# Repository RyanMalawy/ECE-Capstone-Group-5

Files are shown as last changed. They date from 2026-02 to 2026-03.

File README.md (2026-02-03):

# Shoe Insole Pressure Sensor PCB
Schematic and Board Layout for Mizzou ECE Capstone Project

ESP 32 Code

## Repository Rules
When pushing KiCad files, do not push .lck files

## Toolchain
KiCad Version: 9.0

Arduino IDE

## Repository Structure
| Path | Description |
|---|---|
| /Capstone-backups | .zip backups |
| /Hierarchical Sheets | .kicad_sch files |
| /Spice | .kicad_sch files with Spice |
| /Libs | Any imported IC models |
| Capstone.kicad_sch | Root schematic file |
| Capstone.kicad_pro | Project file |
| Capstone.kicad_pcb | PCB file |

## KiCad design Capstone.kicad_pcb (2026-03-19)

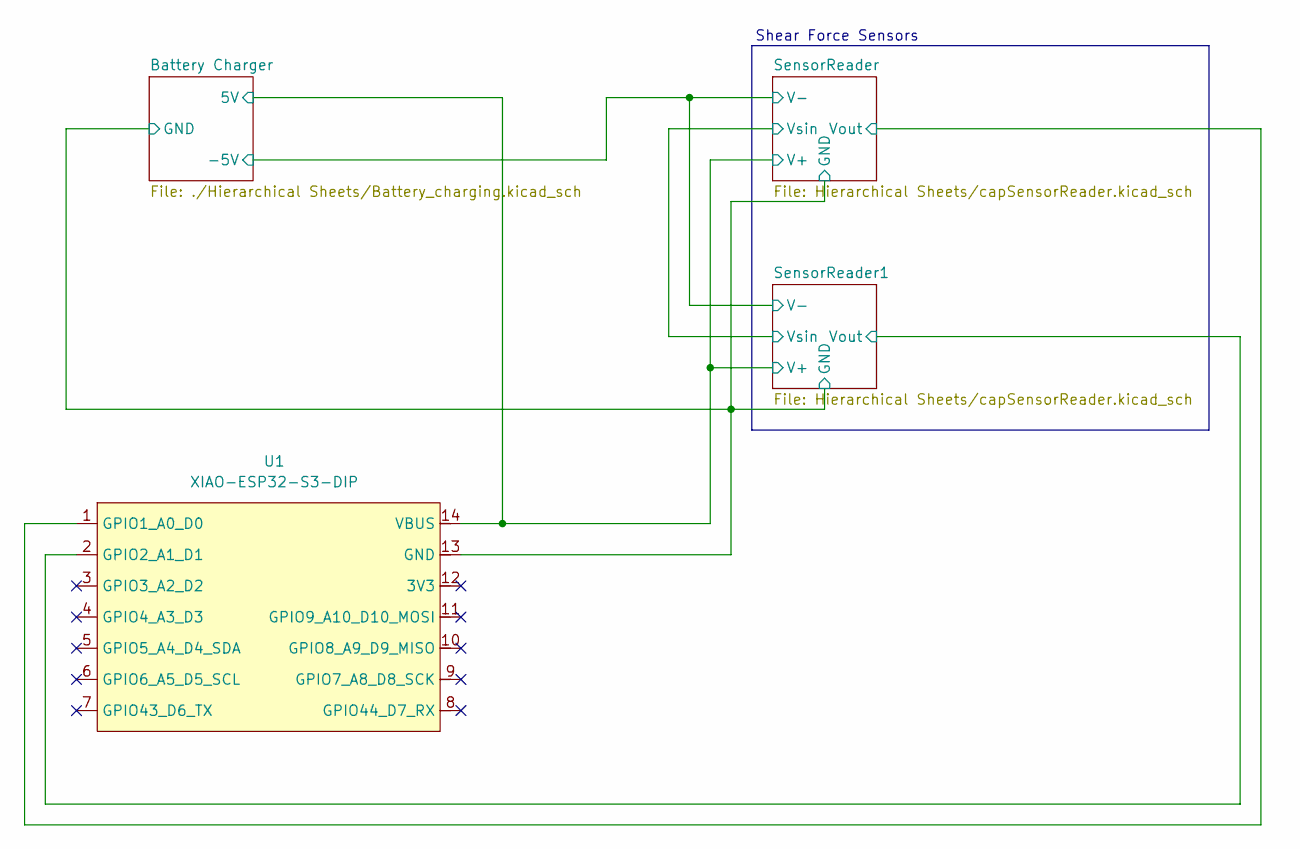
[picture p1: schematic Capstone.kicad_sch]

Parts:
U1: XIAO-ESP32-S3-DIP

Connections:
5V OUT: U1.14 (VBUS); also elsewhere on the board
/SensorReader1/Vout: U1.2 (GPIO2_A1_D1); also elsewhere on the board
/SensorReader/Vout: U1.1 (GPIO1_A0_D0); also elsewhere on the board
GND: U1.13 (GND); also elsewhere on the board

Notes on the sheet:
Shear Force Sensors

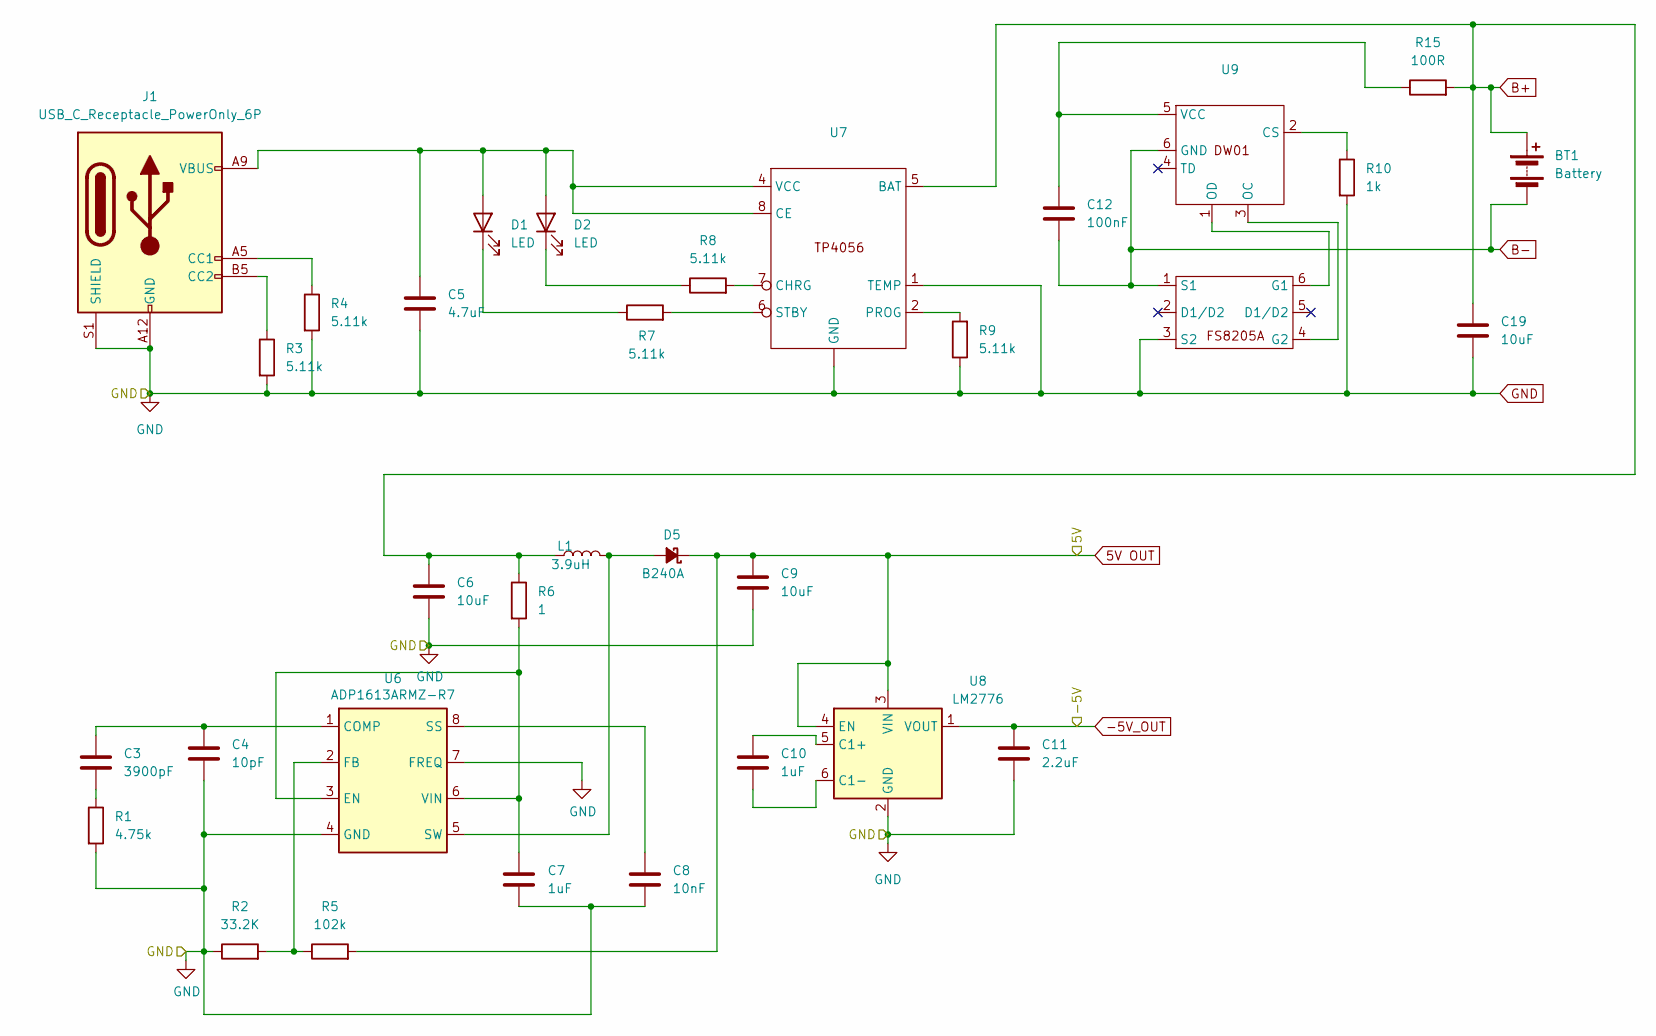
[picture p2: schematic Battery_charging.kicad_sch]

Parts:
BT1: Battery; JST_SUR_BM02B-SURS-TF_1x02-1MP_P0.80mm_Vertical
C3: 3900pF; C_Disc_D3.8mm_W2.6mm_P2.50mm
C4: 10pF; C_Disc_D3.8mm_W2.6mm_P2.50mm
C5: 4.7uF; C_Disc_D3.8mm_W2.6mm_P2.50mm
C6, C9, C19: 10uF; C_Disc_D3.8mm_W2.6mm_P2.50mm
C7, C10: 1uF; C_Disc_D3.8mm_W2.6mm_P2.50mm
C8: 10nF; C_Disc_D3.8mm_W2.6mm_P2.50mm
C11: 2.2uF; C_Disc_D3.8mm_W2.6mm_P2.50mm
C12: 100nF; C_Disc_D3.8mm_W2.6mm_P2.50mm
D1, D2: LED; LED_D3.0mm_Horizontal_O1.27mm_Z6.0mm
D5: B240A; D_SMA
J1: USB_C_Receptacle_PowerOnly_6P; USB_C_Receptacle_GCT_USB4135-GF-A_6P_TopMnt_Horizontal
L1: 3.9uH; L_Bourns-SRN4018
R1: 4.75k; R_Axial_DIN0204_L3.6mm_D1.6mm_P5.08mm_Horizontal
R2: 33.2K; R_Axial_DIN0204_L3.6mm_D1.6mm_P5.08mm_Horizontal
R3, R4, R7, R8, R9: 5.11k; R_Axial_DIN0204_L3.6mm_D1.6mm_P5.08mm_Horizontal
R5: 102k; R_Axial_DIN0204_L3.6mm_D1.6mm_P5.08mm_Horizontal
R6: 1; R_Axial_DIN0204_L3.6mm_D1.6mm_P5.08mm_Horizontal
R10: 1k; R_Axial_DIN0204_L3.6mm_D1.6mm_P5.08mm_Horizontal
R15: 100R; R_Axial_DIN0204_L3.6mm_D1.6mm_P5.08mm_Horizontal
U6: ADP1613ARMZ-R7; MSOP-8_3x3mm_P0.65mm
U7: SOT-23-8
U8: LM2776; SOT-23-6
U9, U10: SOT-23-6

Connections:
5V OUT: C9.1, D5.1 (K), R5.2, U8.3 (VIN), U8.4 (EN); also elsewhere on the board
-5V_OUT: C11.1, U8.1 (VOUT); also elsewhere on the board
B+: BT1.1 (+), C6.1, C19.1, L1.1, R6.1, R15.2, U7.5 (BAT)
B-: BT1.2 (-), C12.2, U9.6 (GND), U10.1 (S1)
GND: C4.2, C5.2, C6.2, C7.2, C8.2, C9.2, C11.2, C19.2, J1.A12 (GND), J1.B12 (GND), J1.S1 (SHIELD), R1.2, R2.1, R3.2, R4.2, R9.1, R10.2, U6.4 (GND), U6.7 (FREQ), U7. (GND), U7.1 (TEMP), U8.2 (GND), U10.3 (S2); also elsewhere on the board
unnamed: C3.2, R1.1
unnamed: C5.1, D1.2 (A), D2.2 (A), J1.A9 (VBUS), J1.B9 (VBUS), U7.4 (VCC), U7.8 (CE)
unnamed: D1.1 (K), R7.1
unnamed: D2.1 (K), R8.1
unnamed: D5.2 (A), L1.2, U6.5 (SW)
unnamed: J1.A5 (CC1), R4.1
unnamed: J1.B5 (CC2), R3.1
unnamed: C3.1, C4.1, U6.1 (COMP)
unnamed: C7.1, R6.2, U6.3 (EN), U6.6 (VIN)
unnamed: R2.2, R5.1, U6.2 (FB)
unnamed: C8.1, U6.8 (SS)
unnamed: R8.2, U7.7 (CHRG)
unnamed: R9.2, U7.2 (PROG)
unnamed: R7.2, U7.6 (STBY)
unnamed: C10.1, U8.5 (C1+)
unnamed: C10.2, U8.6 (C1-)
unnamed: R10.1, U9.2 (CS)
unnamed: C12.1, R15.1, U9.5 (VCC)
unnamed: U9.1 (OD), U10.6 (G1)
unnamed: U9.3 (OC), U10.4 (G2)

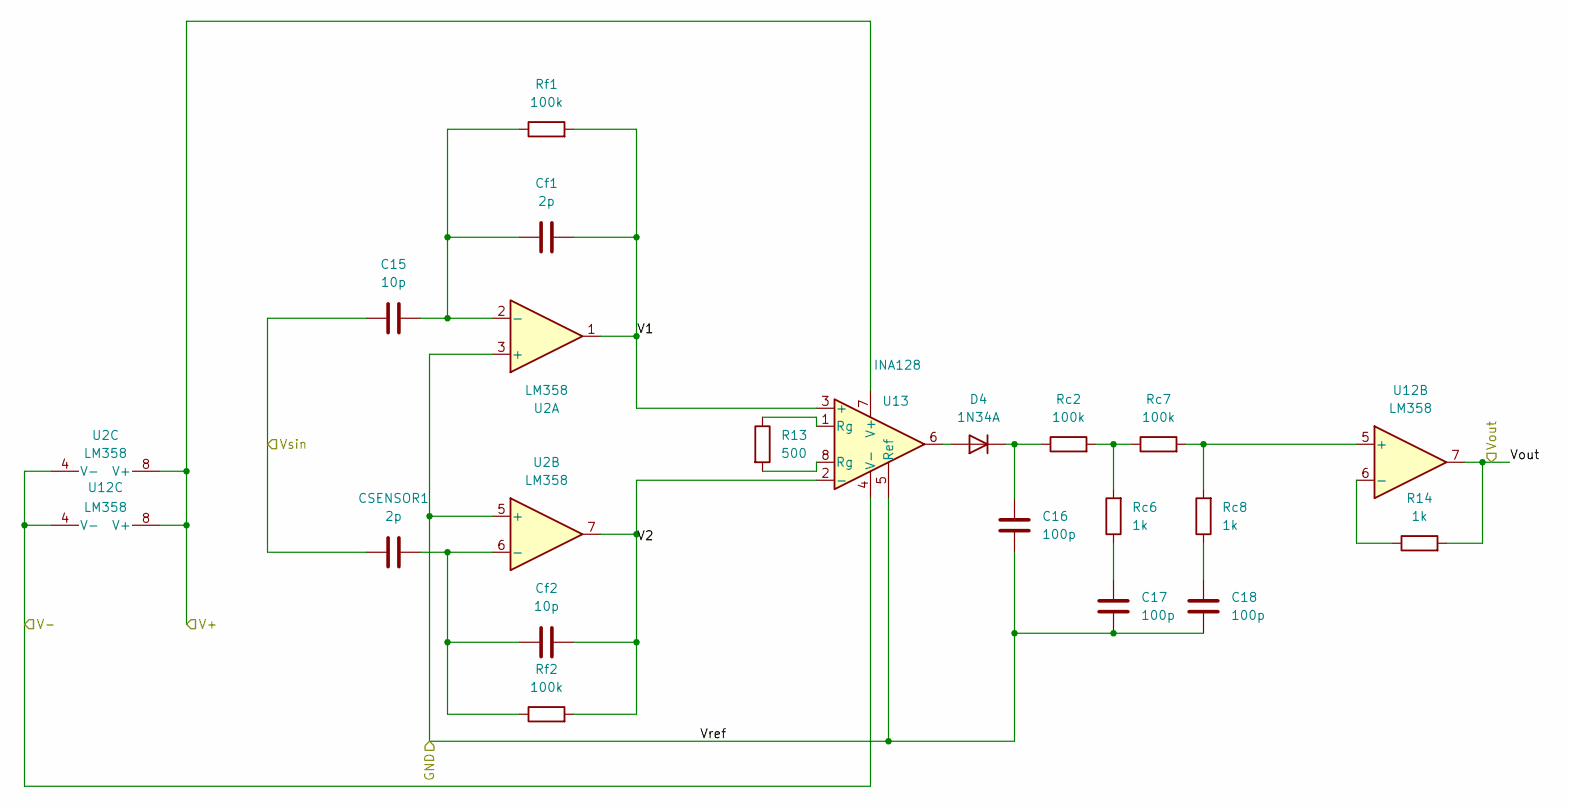
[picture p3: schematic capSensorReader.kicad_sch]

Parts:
C15: 10p
C16, C17, C18: 100p; C_Disc_D3.8mm_W2.6mm_P2.50mm
CSENSOR1: 2p
Cf1: 2p; C_Disc_D3.8mm_W2.6mm_P2.50mm
Cf2: 10p; C_Disc_D3.8mm_W2.6mm_P2.50mm
D4: 1N34A; D_DO-35_SOD27_P2.54mm_Vertical_AnodeUp
R13: 500; R_Axial_DIN0204_L3.6mm_D1.6mm_P5.08mm_Horizontal
R14: 1k; R_Axial_DIN0204_L3.6mm_D1.6mm_P5.08mm_Horizontal
Rc2, Rc7: 100k; R_Axial_DIN0204_L3.6mm_D1.6mm_P5.08mm_Horizontal
Rc6, Rc8: 1k; R_Axial_DIN0204_L3.6mm_D1.6mm_P5.08mm_Horizontal
Rf1, Rf2: 100k; R_Axial_DIN0204_L3.6mm_D1.6mm_P5.08mm_Horizontal
U2, U12: LM358; DIP-8_W7.62mm
U13: INA128; DIP-8_W7.62mm

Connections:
5V OUT: U2.8 (V+), U12.8 (V+), U13.7 (V+); also elsewhere on the board
-5V_OUT: U2.4 (V-), U12.4 (V-), U13.4 (V-); also elsewhere on the board
/SensorReader1/V1: Cf1.2, Rf1.2, U2.1, U13.3 (+)
/SensorReader1/V2: Cf2.2, Rf2.2, U2.7, U13.2 (-)
/SensorReader1/Vout: R14.2, U12.7; also elsewhere on the board
GND: C16.2, C17.2, C18.2, U2.3 (+), U2.5 (+), U13.5 (Ref); also elsewhere on the board
unnamed: C15.1, CSENSOR1.1
unnamed: C17.1, Rc6.1
unnamed: C18.1, Rc8.1
unnamed: D4.2 (A), U13.6
unnamed: C16.1, D4.1 (K), Rc2.1
unnamed: R13.1, U13.1 (Rg)
unnamed: R13.2, U13.8 (Rg)
unnamed: Rc2.2, Rc6.2, Rc7.1
unnamed: Cf1.1, Rf1.1, U2.2 (-)
unnamed: Cf2.1, Rf2.1, U2.6 (-)
unnamed: Rc7.2, Rc8.2, U12.5 (+)
unnamed: R14.1, U12.6 (-)

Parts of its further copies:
C1, C13, C14: 100p; C_Disc_D3.8mm_W2.6mm_P2.50mm
Cf3: 2p; C_Disc_D3.8mm_W2.6mm_P2.50mm
Cf4: 10p; C_Disc_D3.8mm_W2.6mm_P2.50mm
D3: 1N34A; D_DO-35_SOD27_P2.54mm_Vertical_AnodeUp
R11: 1k; R_Axial_DIN0204_L3.6mm_D1.6mm_P5.08mm_Horizontal
R12: 500; R_Axial_DIN0204_L3.6mm_D1.6mm_P5.08mm_Horizontal
Rc1, Rc4: 100k; R_Axial_DIN0204_L3.6mm_D1.6mm_P5.08mm_Horizontal
Rc3, Rc5: 1k; R_Axial_DIN0204_L3.6mm_D1.6mm_P5.08mm_Horizontal
Rf3, Rf4: 100k; R_Axial_DIN0204_L3.6mm_D1.6mm_P5.08mm_Horizontal
U3: INA128; DIP-8_W7.62mm
U4, U5: LM358; DIP-8_W7.62mm

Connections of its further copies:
5V OUT: U3.7 (V+), U4.8 (V+), U5.8 (V+); also elsewhere on the board
-5V_OUT: U3.4 (V-), U4.4 (V-), U5.4 (V-); also elsewhere on the board
/SensorReader/V1: Cf3.2, Rf3.2, U3.3 (+), U4.1
/SensorReader/V2: Cf4.2, Rf4.2, U3.2 (-), U4.7
/SensorReader/Vout: R11.2, U5.7; also elsewhere on the board
GND: C1.2, C13.2, C14.2, U3.5 (Ref), U4.3 (+), U4.5 (+); also elsewhere on the board
unnamed: C13.1, Rc3.1
unnamed: C14.1, Rc5.1
unnamed: D3.2 (A), U3.6
unnamed: C1.1, D3.1 (K), Rc1.1
unnamed: R12.1, U3.1 (Rg)
unnamed: R12.2, U3.8 (Rg)
unnamed: Rc1.2, Rc3.2, Rc4.1
unnamed: Cf3.1, Rf3.1, U4.2 (-)
unnamed: Cf4.1, Rf4.1, U4.6 (-)
unnamed: Rc4.2, Rc5.2, U5.5 (+)
unnamed: R11.1, U5.6 (-)

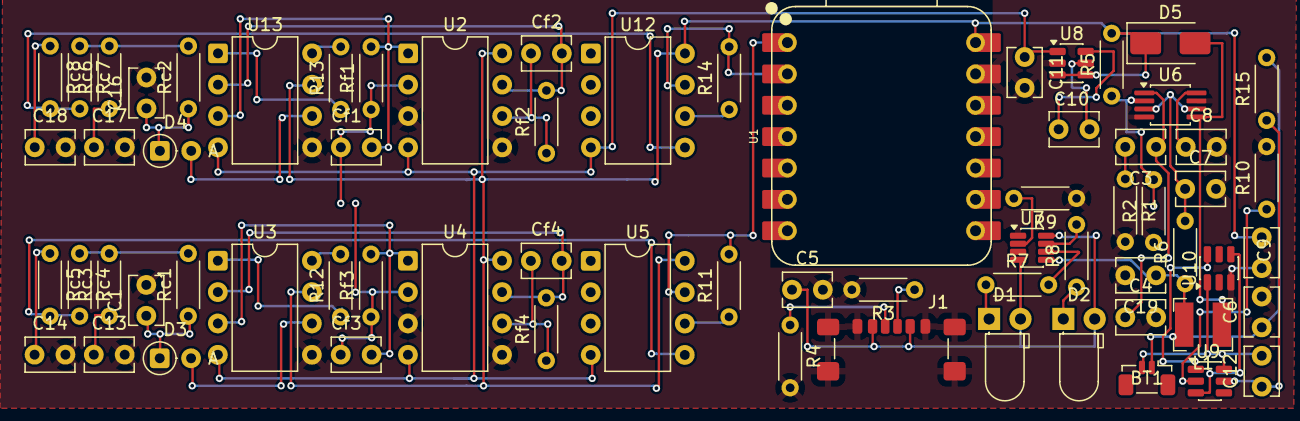
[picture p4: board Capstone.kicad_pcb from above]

Board: 2 copper layers, 68 parts (0 on the bottom side), 53 nets.

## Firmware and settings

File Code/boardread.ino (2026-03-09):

const int ADC_PIN = 4;

void setup() {
  Serial.begin(115200);
  delay(300);
  analogReadResolution(12);            // 0–4095
  analogSetPinAttenuation(ADC_PIN, ADC_11db);
}

void loop() {
  int raw = analogRead(ADC_PIN);

  // Lock Y-axis so the waveform is visible
  Serial.print("0 ");
  Serial.print("4095 ");
  Serial.println(raw);

  delay(5);   // adjust to change time scale
}

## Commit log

2026-02-02 File upload
    [8xAmplifier.kicad_sch, Capstone.kicad_pcb, Capstone.kicad_sch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]
2026-02-03 File organizing
    [8xAmplifier.kicad_sch, Capstone.kicad_sch, amplifier.kicad_sch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]
2026-02-06 SN74HC161DR symbol update
    [Capstone.kicad_sch]
2026-02-06 Added Project Component Libary
    CapstoneComps libary for project specific components
    also added Capstone.kicad_prl to .gitignore
2026-02-06 Added New Libraries
    ESP32 Library - Footprint & Schematics
    Binary Counter Footrprint Added
    [Capstone.kicad_sch]
2026-02-06 Update .gitignore update PCB footprints
    [Capstone.kicad_pcb, Capstone.kicad_sch, amplifier.kicad_sch]
2026-02-06 Update Root
    Working on simulations
    [Capstone.kicad_pcb, Capstone.kicad_sch, Sheet-Template.kicad_sch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]
2026-02-07 layout of amplifier 1 - begin
    [amplifier.kicad_sch]
2026-02-08 Continued researching IA topologies and design strategies -- updated amplifier schematics with 2 Op Amp topology
    [amplifier.kicad_sch]
2026-02-08 Cited a source for the instr amp topology
    [amplifier.kicad_sch]
2026-02-09 Contined looking into topologies and general op amp information - added notes to amplifier schematics.
    [amplifier.kicad_sch]
2026-02-09 remove Hierarchical Sheets folder inside Hierarchical Sheets foler
    [8xAmplifier.kicad_sch, amplifier.kicad_sch]
2026-02-09 Binary Cleanup
    [Testing.kicad_sch]
2026-02-09 Switched to pre-made instr. amp. - made preliminary choice of IA
    [amplifier.kicad_sch]
2026-02-09 changed the description on the buffer op amp in amplifier schematic
    [amplifier.kicad_sch]
2026-02-10 Added new INA350CDS to part library and placed it into the schematic
    [amplifier.kicad_sch]
2026-02-12 Added 2nd order low-pass filter topology - Still working on exact design
    [amplifier.kicad_sch, filter.kicad_sch]
2026-02-13 added battery charger
    [Battery_charging.kicad_sch]
2026-02-13 Link Battery Charger
    [Battery_charging.kicad_sch, Capstone.kicad_sch, filter.kicad_sch]
2026-03-09 Sensor Reading Circuit
    [capSensorReader.kicad_sch]
2026-03-09 Redo Base Project file add code
    [Battery_charging.kicad_sch, Capstone.kicad_pcb, Capstone.kicad_sch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]
2026-03-12 Added rectifier and passive low-pass filter (RC)
    [capSensorReader.kicad_sch]
2026-03-13 Better Sensor Reader
    [capSensorReader.kicad_sch, capSensorReaderINA.kicad_sch]
2026-03-16 Update Main Sub Sheets
    [Capstone.kicad_sch, capSensorReader.kicad_sch]
2026-03-16 Main Update
    [Capstone.kicad_sch, capSensorReader.kicad_sch]
2026-03-16 Battery Charging Moved
    [Battery_charging.kicad_sch]
2026-03-16 PCB designed rev1.0
    [Battery_charging.kicad_sch, Capstone.kicad_pcb, Capstone.kicad_sch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]
2026-03-19 Remove Ground fill around ESP 32
    [Capstone.kicad_pcb]
2026-03-31 Added ocsillator + logic circuit (in-progress)
    [capstone_oscillator.kicad_sch]
2026-03-31 continued work on osc/logic circuit
    [capstone_oscillator.kicad_sch]
2026-04-01 timer oscillator
    [capstone_oscillator.kicad_sch]
2026-04-01 timer oscillator circuit
2026-04-01 Remove extra ref sensor
    each module had a reference sensor before, now have single ref sensor comparing to both sensors
    [Battery_charging.kicad_sch, Capstone.kicad_pcb, Capstone.kicad_sch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]
2026-04-13 Revert "Remove extra ref sensor"
    This reverts commit 7f0b0207ac24b991faee57c630f393e10dd69dda.
    [Battery_charging.kicad_sch, Capstone.kicad_pcb, Capstone.kicad_sch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]
